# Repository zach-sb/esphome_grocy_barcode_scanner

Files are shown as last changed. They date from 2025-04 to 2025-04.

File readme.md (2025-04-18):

# ESPHome Grocy Barcode Scanner

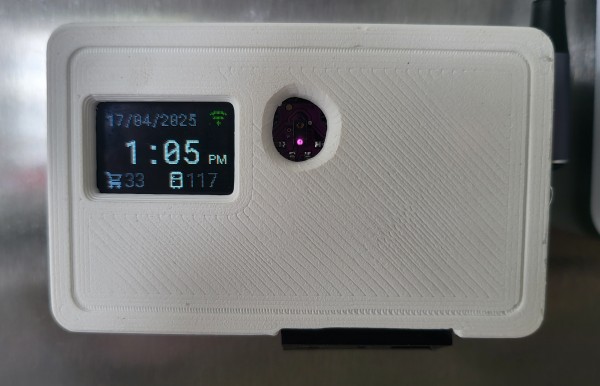
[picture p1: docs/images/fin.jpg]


[Demo Video](https://youtube.com/shorts/6EKOk3bfEmU?feature=share)

This is the latest effort in my attempts to actually make use of Grocy in my house. Grocy is a very cool looking way to keep track of your groceries, however it is very powerful. With great power, comes great complexity, and this great complexity generally leads to adoption difficulties.

We have found that when bringing the shopping home it really is just too much effort to consistently get a phone, find the app, open the app and get the right scanner mode running. The hope is by introducing a dedicated barcode scanner that can easily accessed, that obstacle would be removed.

Also, I just wanted to make a cool barcode scanner.

Special thanks goes to [MattFryer's HA-mealie-Barcode-Scanner](https://github.com/MattFryer/HA-Mealie-Barcode-Scanner), most of the code for interacting with the GM67 barcode scanner came from their work. Their readme contains a lot of useful information. In particular, the notes about setting it into UART mode, and how the wires are non standard colors.

> [!WARNING]
> You may think you can substitute another barcode scanner instead of the GM67. While you may have success with this, DO NOT GET A GM60 (round with a rgb ring). It sucked. GM67 is way better and worked perfectly in this project. 

## Features
- Can scan any barcode supported by the [GM67 scanner](http://www.growbarcode.com/productinfo/888736.html)
- On a scan, can:
  - Add item to stock
  - Remove item from stock
  - Open item in stock
  - Look up item stock
  - Add item to shopping list (WIP)
- Navigate menu with gestures (swipes) in front of unit
- Display simple information on screen
  - Current Mode
  - Product Scanned
  - Product Stock
- Info screen
  - Can be toggled (such as when user in room) to prevent screen burn in
  - Shows
    - Time
    - Date
    - Current Stock Count
    - Current Shopping list count
- When paired with a TTS enabled voice assistant in Home Assistant (Such as the [Home Assistant Voice PE](https://www.home-assistant.io/voice-pe/))
  - Speak current action
  - Speak current stock levels 

## Assumptions
- You have a [Home Asisstant](https://www.home-assistant.io/) instance
- You have the [Grocy Custom Integration](https://github.com/custom-components/grocy) added.
  - The Grocy integration requires HACS, however it is only actually used to provide the numbers for the info page on the scanner's screen. All the other actions are actually done through REST commands. Thus, this step is actually quite optional.
- You have a [Grocy](https://grocy.info/) instance 
- You have [ESPHome](https://esphome.io/) setup and ready to go
- Your Home Assistant can reach your Grocy install

## Hardware

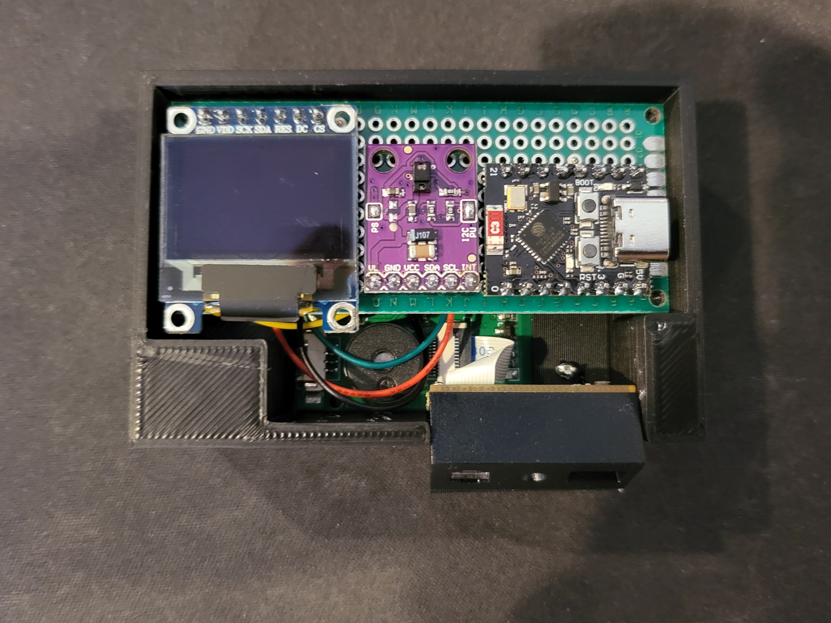
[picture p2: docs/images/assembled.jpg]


### Bill of Materials
Prices are approximate

| Image | Item | Cost (AUD) |
| --- | --- | --- |
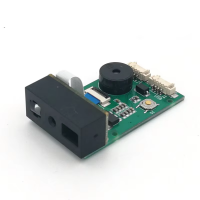
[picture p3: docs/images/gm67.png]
|  | GM67 UART Barcode Scanner | \$30 |
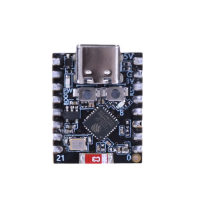
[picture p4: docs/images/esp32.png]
| | ESP32-C3 Mini | $5
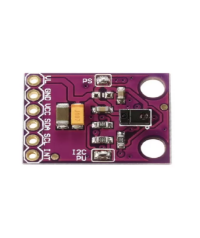
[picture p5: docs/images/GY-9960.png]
|  |  GY-9960-3.3 APDS-9960 RGB Infrared Gesture Sensor |$5 |
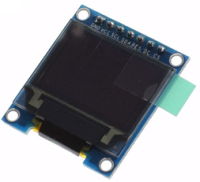
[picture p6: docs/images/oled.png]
| | SSD1331 0.95 inch Color OLED | $10|
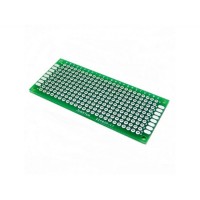
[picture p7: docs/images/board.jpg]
| | 3x7cm Prototype Board |$2 |
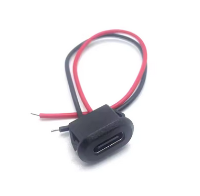
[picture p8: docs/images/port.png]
| | USB C-type 2 pin connector socket with buckle | $0.40 |
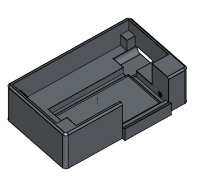
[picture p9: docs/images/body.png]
| | Printed Case Body | $0.65|
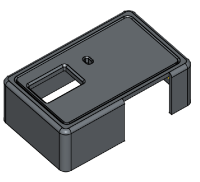
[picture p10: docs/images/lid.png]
| | Printed Case Lid | $0.55 |
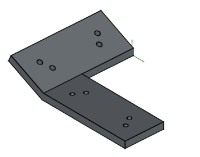
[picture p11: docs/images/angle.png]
| | Printed Angle Adaptor | $0.05 |
| | One M3 screw, no longer than 16mm| |
| | Wires | |
| | Magnets, if attaching to Fridge | |

### Diagram

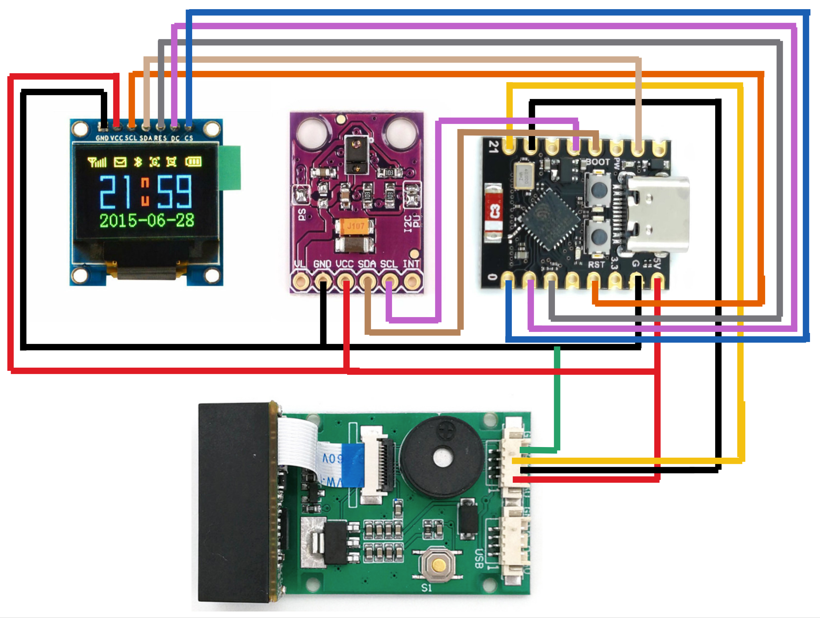
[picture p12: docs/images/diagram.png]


### 3D Printing
If you use the board shown in the BOM, and align as shown in the image above, [this case](https://www.printables.com/model/1267415-esphome-grocy-barcode-scanner) (also in the 3D Models folder) will work for you.

## Software
### ESPHome
Create a new device in ESPHome, and use the code in `barcode-scanner.yaml`. In particular, pay attention to the substitutions section at the top, and update as needed. If you use a different ESP board, you may want to use different pins.

Also change the HA Sensors section as you see fit. If you don't use the grocy integration here, you shouldn't need it at all. 

```yaml
substitutions:
  # Names
  device_id: kitchen-barcode-scanner
  device_name: Kitchen Barcode Scanner

  # UART Pins for the Barcode Scanner
  uart_tx_pin: GPIO21
  uart_rx_pin: GPIO20

  # i2C for Gesture Sensor
  i2c_sda_pin: GPIO08
  i2c_scl_pin: GPIO09

  # SPI and Display Pins
  spi_clk_pin: GPIO4
  spi_mosi_pin: GPIO6

  diplay_cs_pin: GPIO0
  display_dc_pin: GPIO1
  diplay_reset_pin: GPIO2

  # HA Sensors for info screen
  ha_sensor_1: sensor.grocy_shopping_list
  sensor_icon_1: mdi:cart-outline
  sensor_1_color: "838996"

  ha_sensor_2: sensor.grocy_stock
  sensor_icon_2: mdi:fridge-outline
  sensor_2_color: "ffffff"

  # Timezone
  timezone: Australia/Sydney
  ```

**Why set a timezone?**
The display shows a clock, and I have this issue I haven't bothered figuring out that makes my ESPHome devices show the wrong time unless I explicitly set the timezone on them. If you don't have this issue, you could just remove the timezone setting from here

```yaml
time:
  - platform: homeistant
    id: homeistant_time
    timezone: ${timezone} # <-- Remove this
```

### Home Assistant

#### config

Add the `rest_commands` found in the `Home Assistant Grocy Scripts.yml` file to your Home Assistant config file (currently there is no UI for this :(). Replace `[GROCY_URL]` and `[GROCY_API_KEY]`.

**Why not use the Grocy Integration here?**
If there was an error response (such as trying to open a product when stock was 0), the error would just stop the automation. Using a rest api call also shows the exact error message we get, which allows us to work with it.

#### Automations
Use the code in `Home Assistant Grocy Barcode Scan Automation.yml` to build an automation. Check enitity names are correct.

The rough flow of the automation is this:

```mermaid
graph TD;
    s(Start);
    lup(LookupBarcode);
    e1(if Error);
    e1_1(No Match);
    e1_2(Other Error);
    s1(if Success);

    r1(report Error);

    s --> lup
    lup --> e1
    lup --> s1

    e1 --> e1_1
    e1 --> e1_2

    e1_1 --> r1
    e1_2 --> r1

    cm1(Check Current Mode)

    s1 --> cm1

    cc1(Call correct REST Action)

    cm1 --> cc1

    e2(if Error);
    e1_1(No Match);
    s2(if Success);    
    r2(report Error);
    cc1 --> e2
    cc1 --> s2
    e2 --> r2

    r3(Report Success)
    s2 --> r3
```

(**Note**: this graph isn't accounting for a couple extra branches of what exactly is going on for each different action. You can see that in the traces after adding the automation)

**Note**: I also suggest setting up an automation to toggle the info screen so that it is only shown when someone might be looking at it, otherwise I imagine burn in may be an issue.

## Known Issues
- The GM67 will always turn on the scanner when powered. Currently, the ESP device sends a command to turn it off as part of it's boot process. Perhaps this could happen faster?
- The hole for the gesture sensor in the printed lid is far too small. I solved this by using a drill until it started working. The model should be corrected to find the correct hole size and placement.

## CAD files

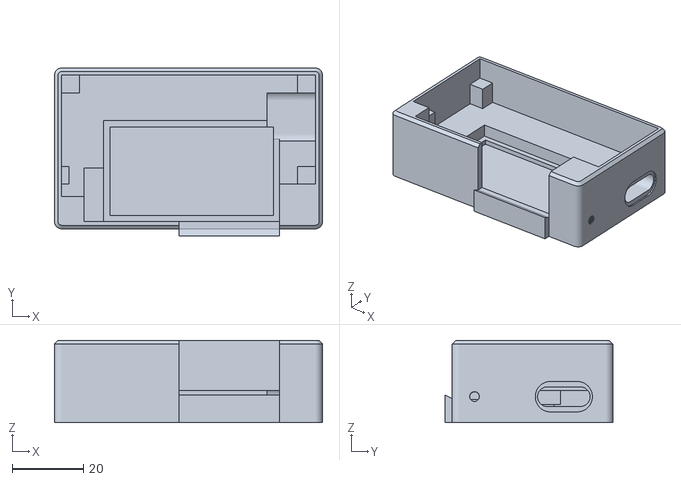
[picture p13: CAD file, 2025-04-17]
3d Models/Base.stl
75.0 x 47.0 x 23.0

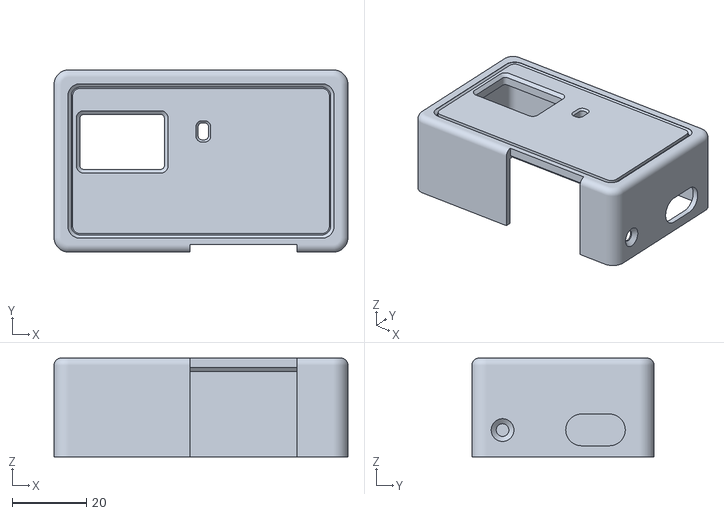
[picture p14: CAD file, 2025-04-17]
3d Models/Lid.stl
79.0 x 49.0 x 26.6

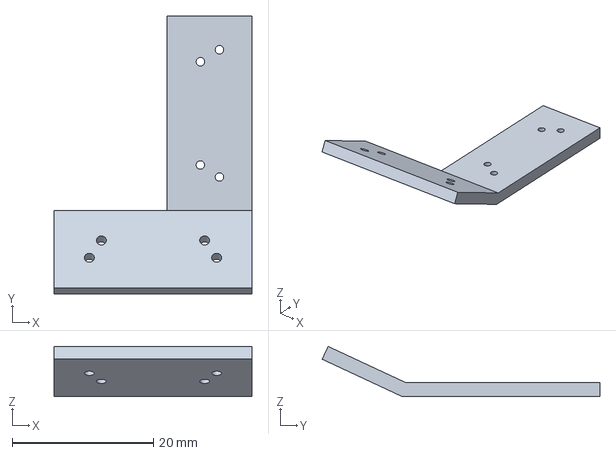
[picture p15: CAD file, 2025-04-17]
3d Models/Angle Adapter.FCStd
28.0 x 39.3 x 7.10 mm

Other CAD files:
3d Models/Angle Adapter.stl
